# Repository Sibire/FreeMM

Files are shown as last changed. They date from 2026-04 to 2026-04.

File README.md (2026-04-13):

# DIYgitizer

A Do-It-Yourself 5-DOF digitizer arm / coordinate measuring machine for under $200.

DIYgitizer arm

# So what is it?

The DIYgitizer is a passive (no motors), manually-operated measuring arm. Magnetic encoders within each joint track their angles, forward kinematics computes the probe tip position in three dimensions, and a desktop app captures the data and works its various magics.

## Why on Earth would you make this?

For roughly the same reasons I did. I got tired of eyeballing dimensions on things I bought, had a drone frame I couldn't find a drawing of, and figured I could use a little project to keep myself busy. Also, I didn't feel like buying a 3D scanner, don't own an iPhone, and didn't have the cash to blow on a multi-thousand-dollar machine. I figured I could get around some accuracy issues by making adjustable drawings, instead. Now we're here.

**Modes of Operation**

- **CMM Mode** — Like any coordinate measurement machine, this mode captures individual points, measures the distances between them, and exports them for review. It's not nearly as accurate as a $35,000 stand-alone device might be, but it's also orders of magnitude cheaper, so there's that.
- **3D Digitizer Mode** — Run the probe over a surface to scan it continuously, building a point cloud, mesh, or parametric model. Then, export to Fusion (or whatever you're using) as a PLY, STL, or STEP file.
- **2D Trace Mode** — Trace an object's outline, auto-detecting lines, arcs, and circles, and export their dimensions as a DXF or SVG drawing.
  
To maximize the user's ability to compensate for measurement errors, all shapes are broken down into their most basic primitives. This means lines, arcs, circles, planes, cylinders, spheres, and the like, all with dimensioned offsets. No splines, because manually editing those when you don't know the existing dimensions is exactly the sort of headache I'm building this entire project specifically to avoid. Every measurement is an individual dimension you can edit in Fusion, or some other software of your choice.

## Hardware

### Kinematic Chain

```
Base Plate (clamped to desk)
  └─ J1: Base Yaw (360°)
       └─ Turret
            └─ J2: Shoulder Pitch (±105°)
                 └─ Upper Arm (300mm aluminum tube)
                      └─ J3: Elbow Pitch (±145°)
                           └─ Forearm (300mm aluminum tube)
                                └─ J4: Wrist Pitch (360°)
                                     └─ J5: Wrist Pitch 2 — perpendicular to J4 (±145°)
                                          └─ Probe (1mm ruby ball)
```

### Electronics

| Component | Details |
|---|---|
| 1x MCU | ESP32 (38-pin) |
| 5x Encoders | AS5600 (12-bit magnetic, I2C. 23x23mm with M3 holes 16mm apart) |
| 1x I2C Mux | TCA9548A Breakout Board(resolves shared AS5600 address) |
| 1x Display | 0.96" SSD1306 OLED I2C (Make sure yours is square, 28x28mm) |
| 3x Buttons | Sample (GPIO 26), Mode (GPIO 27), Foot Pedal Sample (GPIO 25) |

### Bill of Hardware

REQUIRED:
| Component | Details |
|---|---|
| 2x 8mm OD x 300mm Aluminum tubing | Arm structure |
| 4x M2x6mm Screws | OLED mount |
| 22x M3x6mm Screws | 4x5 Encoder mount, 2x Mux mount |
| 6x M5x12mm Screws | 4x Base clamp. 2x Foot pedal |
| 1x 2mm Thread insert | Probe swivel (4mm Preferred) |
| 1x M2 1mm Probe Tip | Adjust J5 length to center of probe tip |
| Two-wire shielded cable | Still working out exact length |
| 22 AWG wire | See above |
| Double-sided tape | Keep the MCU in place) |
| A whole lot of zipties and heat shrink | Tidying things up |
| Hot Glue | Gluing the buttons in place, literally whatever else it might be used for |

PREFERRED:
| Component | Details |
|---|---|
| 4x M5 Thread inserts | Base clamp, part is 3.75mm thick, so smaller the better, but it's not terribly critical |
| 2x M10 Thread inserts | Base clamp, in case print tolerances are off for the table clamping bolts |
| 2x M10x75mm Bolts | Base clamp, see above |

### Print List

| Component | Details |
|---|---|
| 1x Base | Holds it all together |
| 1x Base Clamp | Fits into base for desk mounting |
| 2x Base Clamp Screw | Secures base clamp to desk |
| 2x Sensor Swivel | Contains a magnet to interface with one encoder, and the mount for another |
| 2x Sensor Elbow | Contains a mount for an encoder, a slot for 8mm tubing, and sights for alignment with sensorless swivel |
| 2x Sensorless Swivel | Contains a magnet to interface with an encoder, a slot for 8mm tubing, and signts for alignment with elbow |
| 1x Probe Swivel | Holds sample button and probe tip |
| 5x Encoder Lid | Covers encoder compartments |
| 1x Display Lid | Covers OLED circuitry |
| 1x Base Lid | Covers MCU/Mux compartment |
| 1x Foot Pedal Base | It's a pedal base |
| 1x Foot Pedal Top | It's a pedal top |
| 1x Calibration Stop | Slots into base to lock turret alignment for calibration |

All printed parts are PETG (40% infill, 4 walls) with the exception of the Base (10%) and the Base Clamp (15%). You can find an existing set of slices (albeit for an Ender 5 Pro with a MicroSwiss all-metal-hotend and direct drive setup on TH3D firmware) within the repo. Total cost of $Free.99 to $200, depending on what you have on hand.

If your Mux board doesn't fit the base lid's screw posts, use the bare lid and some tape.

## Software

### Desktop App (Python / PyQt5)

```
cd desktop
pip install -r requirements.txt
python run.py
```

Check **Simulator** and click **Connect** to test without hardware.

**Features:**
- Live XYZ + joint angle readout
- CMM mode with point table and dimension list
- 3D viewport (OpenGL) with point cloud, mesh preview, and feature detection overlays
- 2D canvas with fitted features and dimension annotations
- Calibration wizard (1-2-3 block)
- Measurement rounding: 1mm / 0.1mm / 0.01mm (user setting)
- Export: DXF, SVG, PLY, CSV, STL, STEP

**Dependencies:** PyQt5, PyOpenGL, pyserial, numpy, scipy, ezdxf, trimesh. Optional: open3d (mesh), cadquery (STEP).

### Firmware (C++ / PlatformIO)

```
cd firmware
pio run                  # compile
pio run --target upload  # flash to ESP32
pio device monitor       # watch serial output
```

Streams `ANGLES,j1,j2,j3,j4,j5` at ~200Hz over USB serial (115200 baud). Responds to commands: `p` (sample point), `t` (toggle trace), `1`/`2`/`3` (set trace plane), `r` (reset).

### Link Lengths

The forward kinematics uses center-to-center joint distances. These are defined in `firmware/src/config.h` and `desktop/diygitizer/config.py`:

```
BASE_HEIGHT = 38mm      # base plate surface to J2 axis
UPPER_ARM   = 330.1mm   # J2 to J3
FOREARM     = 330.1mm   # J3 to J4
WRIST_LINK  = 36mm      # J4 to J5
PROBE_LEN   = 77.3mm    # J5 to ruby ball center
```

## Calibration

Use a 1-2-3 block (25.4 × 50.8 × 76.2mm). They're cheap, precise enough, and easy to find. The app's calibration wizard will walk you through touching each face, then compute scale factors and joint offsets to minimize error. Without precision parts, you'll want to do this *often*.

## Accuracy

- AS5600: ±1° typical (12-bit)
- Expected tip accuracy: ±1-2mm calibrated, ±3-5mm uncalibrated
- Probe compensation: 0.5mm ball radius, applied automatically
- This is a digitizer, not a metrology instrument. It's designed to beat the Mk. 1 Eyeball, that's about it.

## Project Structure

```
DIYgitizer/
├── firmware/                    # ESP32 PlatformIO project
│   ├── platformio.ini
│   └── src/
│       ├── main.cpp             # Main loop
│       ├── config.h             # Pins, link lengths, constants
│       ├── encoders.*           # AS5600 via TCA9548A mux
│       ├── kinematics.*         # 5-DOF forward kinematics
│       ├── serial_protocol.*    # USB serial protocol
│       ├── buttons.*            # Debounced input
│       ├── display.*            # SSD1306 OLED
│       └── modes.*              # State machine
│
└── desktop/                     # Python desktop app
    ├── run.py                   # Entry point
    ├── requirements.txt
    └── diygitizer/
        ├── app.py               # MainWindow + DataStore
        ├── config.py            # Link lengths, rounding
        ├── connection/          # Serial + simulator
        ├── models/              # Data classes
        ├── modes/
        │   ├── cmm/             # Point capture + dimensions
        │   ├── digitizer/       # 3D scan + mesh + features
        │   └── trace/           # 2D trace pipeline
        ├── calibration/         # 1-2-3 block wizard
        ├── export/              # DXF, SVG, PLY, STL, STEP, CSV
        └── widgets/             # Shared UI components
```

## Status

- [x] Full CAD assembly in Fusion 360
- [x] ESP32 firmware (5-DOF FK, serial protocol, OLED, buttons)
- [x] Desktop app with all three modes
- [x] Geometry pipeline (2D feature fitting)
- [x] 3D feature detection (RANSAC plane/sphere/cylinder)
- [x] Export: DXF, SVG, PLY, STL, STEP, CSV
- [x] Calibration wizard
- [x] Built-in simulator
- [ ] Print and assemble hardware
- [ ] Measure actual link lengths from assembly
- [ ] First real-hardware test
- [ ] Tune calibration procedure

## License

TBD

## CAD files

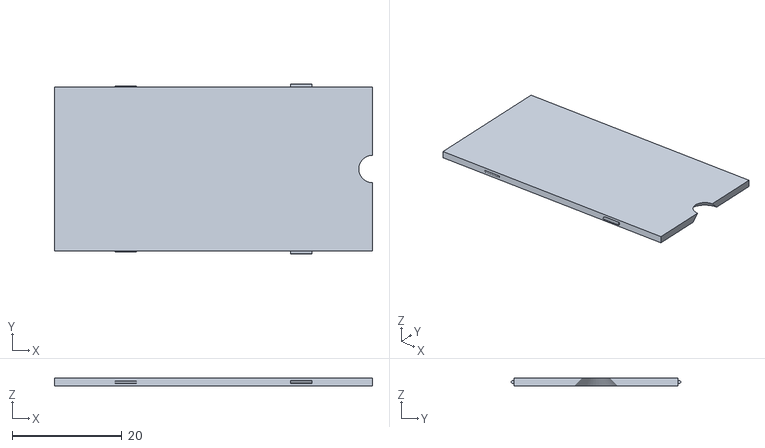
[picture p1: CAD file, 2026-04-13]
models/STL Files/Base Lid Bare.stl
58.0 x 31.0 x 1.50

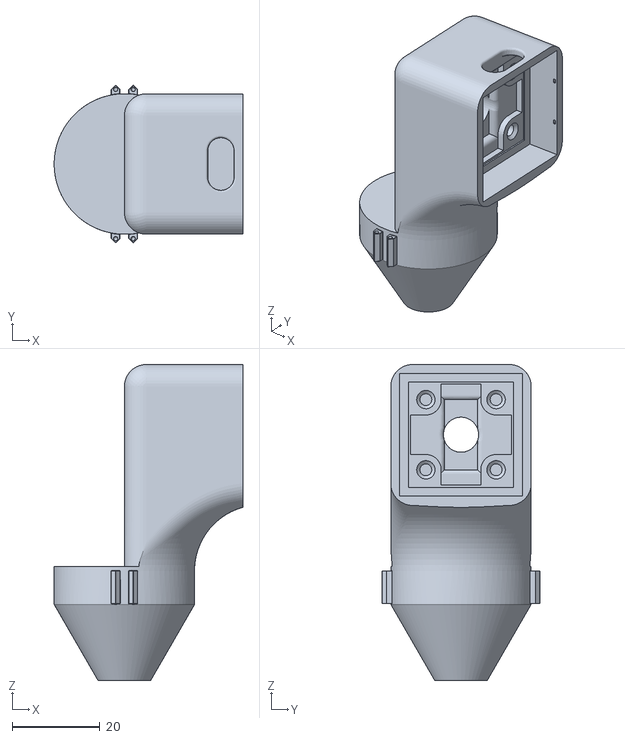
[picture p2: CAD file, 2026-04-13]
models/STL Files/Sensor Elbow.stl
43.0 x 35.9 x 72.0

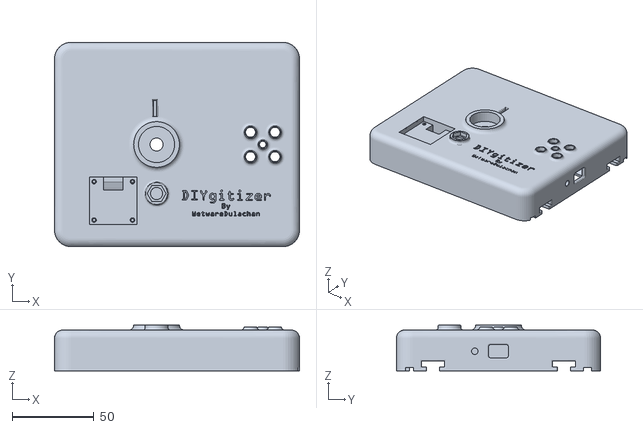
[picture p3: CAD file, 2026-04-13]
models/STL Files/Base.stl
150.0 x 125.0 x 28.0

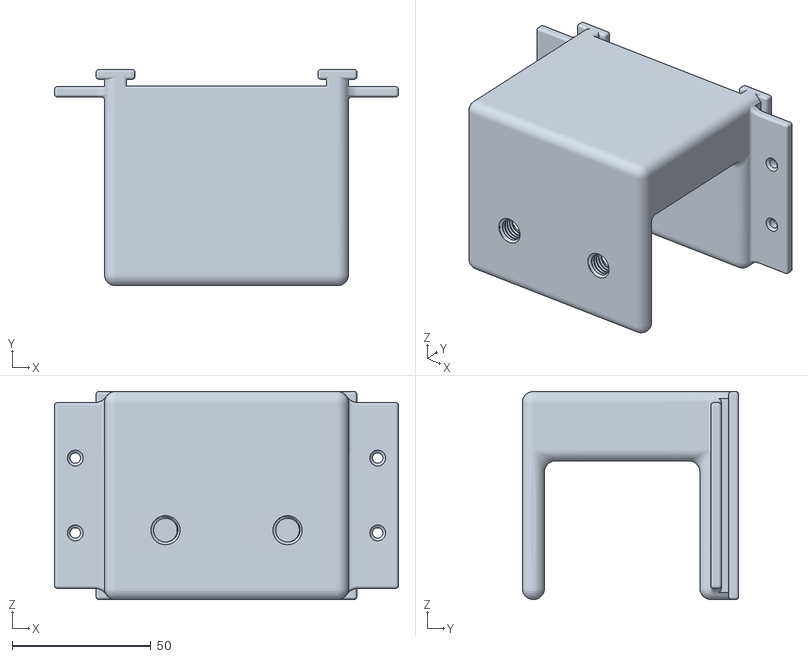
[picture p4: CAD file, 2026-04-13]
models/STL Files/Base Clamp.stl
124.0 x 78.0 x 75.0

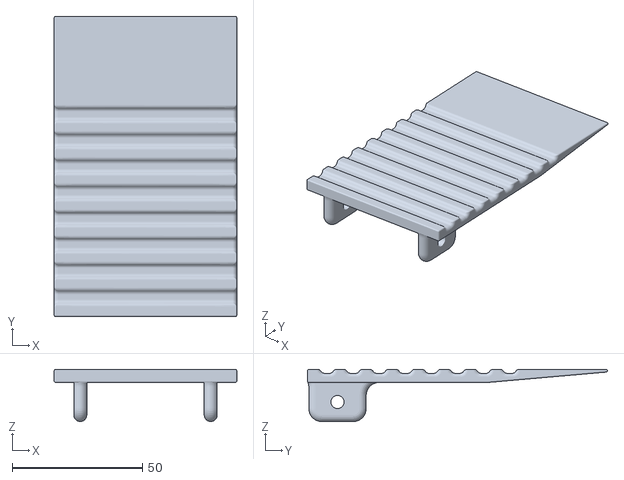
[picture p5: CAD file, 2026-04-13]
models/STL Files/Foot Pedal Top.stl
70.0 x 115.0 x 20.0

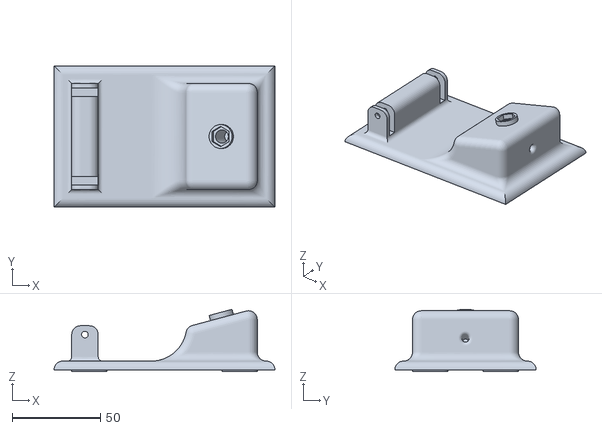
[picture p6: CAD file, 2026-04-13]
models/STL Files/Foot Pedal Base.stl
125.0 x 80.0 x 35.3

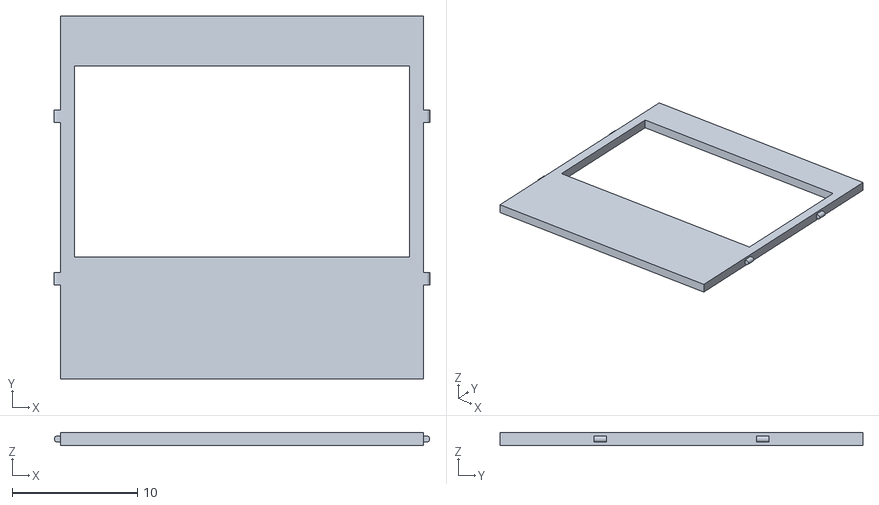
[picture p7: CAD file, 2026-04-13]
models/STL Files/Display Lid.stl
30.0 x 29.0 x 1.00

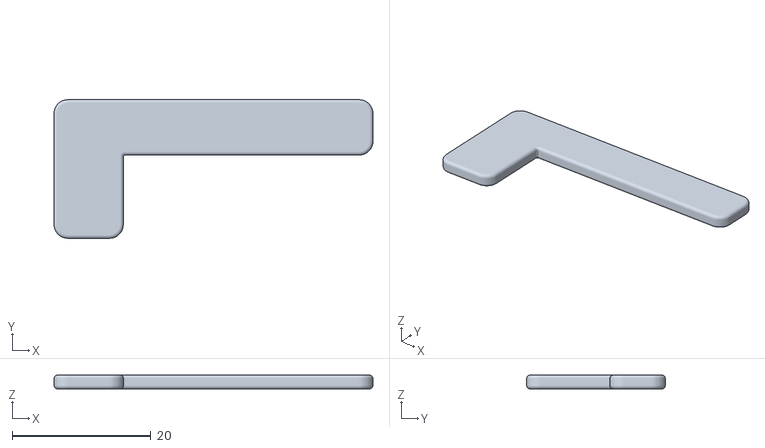
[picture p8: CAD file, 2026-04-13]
models/STL Files/Calibration Stop.stl
46.0 x 20.0 x 2.00

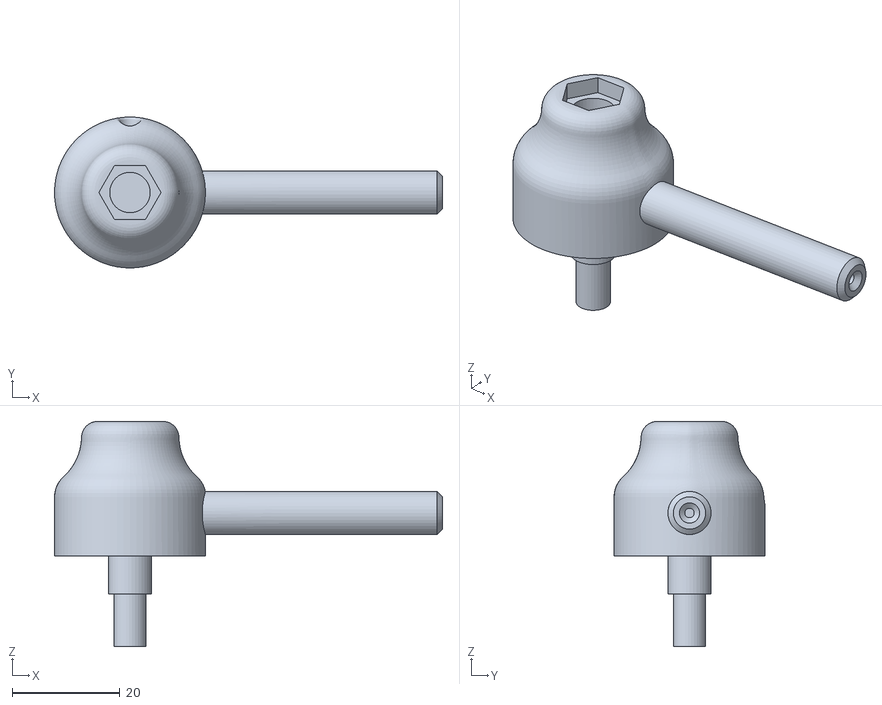
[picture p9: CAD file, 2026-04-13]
models/STL Files/Probe Swivel.stl
72.0 x 28.0 x 41.8

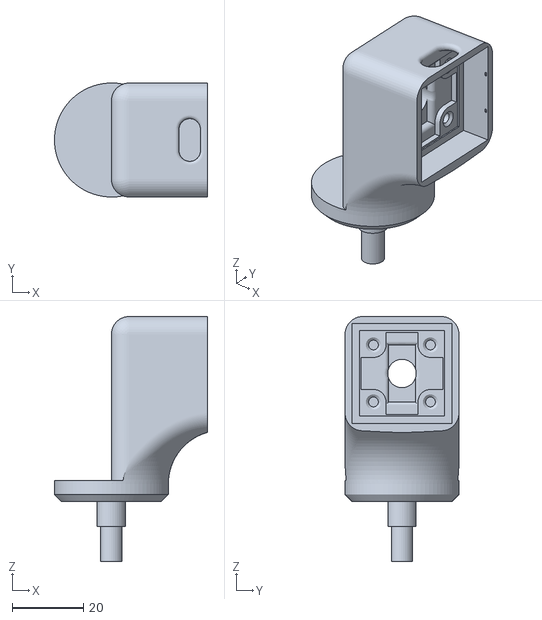
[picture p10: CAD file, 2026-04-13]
models/STL Files/Sensor Swivel.stl
43.0 x 32.0 x 68.8

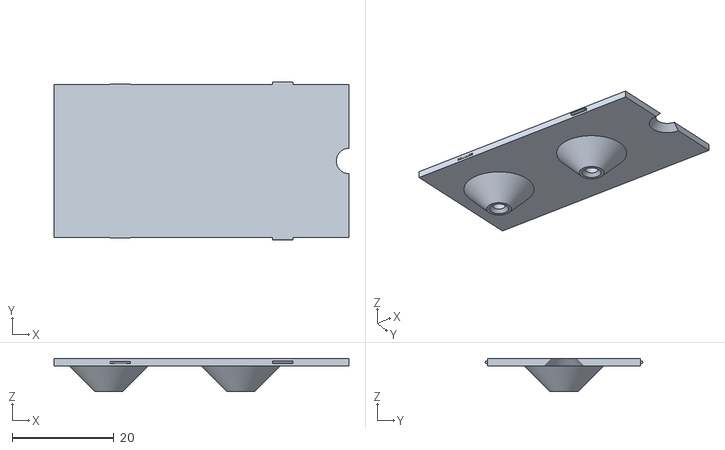
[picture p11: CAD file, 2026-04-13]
models/STL Files/Base Lid.stl
58.0 x 31.0 x 6.50

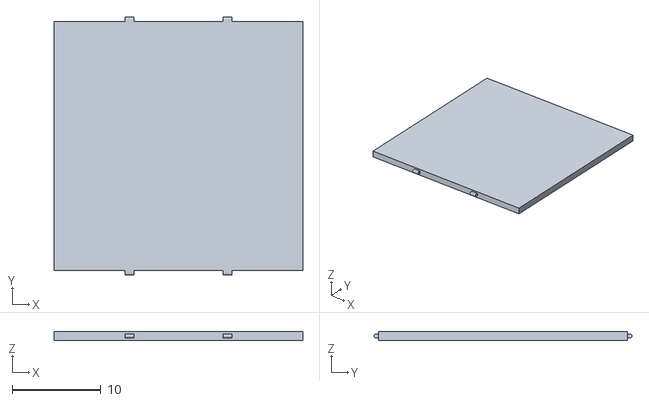
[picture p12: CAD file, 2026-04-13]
models/STL Files/Encoder Lid.stl
28.0 x 29.0 x 1.00

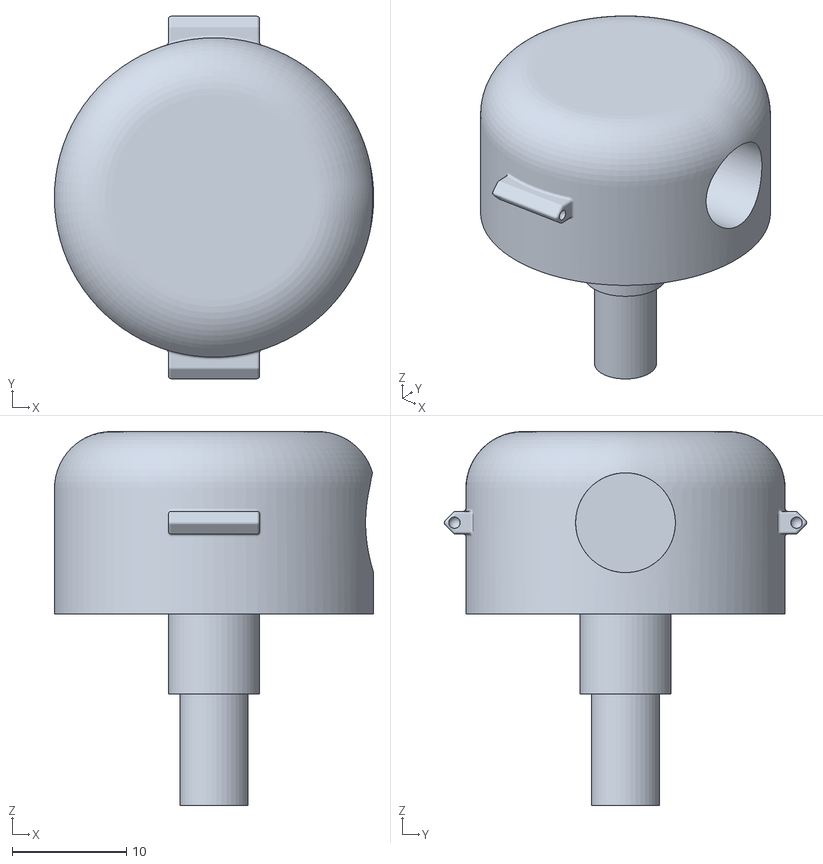
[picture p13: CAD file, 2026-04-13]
models/STL Files/Sensorless Swivel.stl
28.0 x 31.8 x 32.8

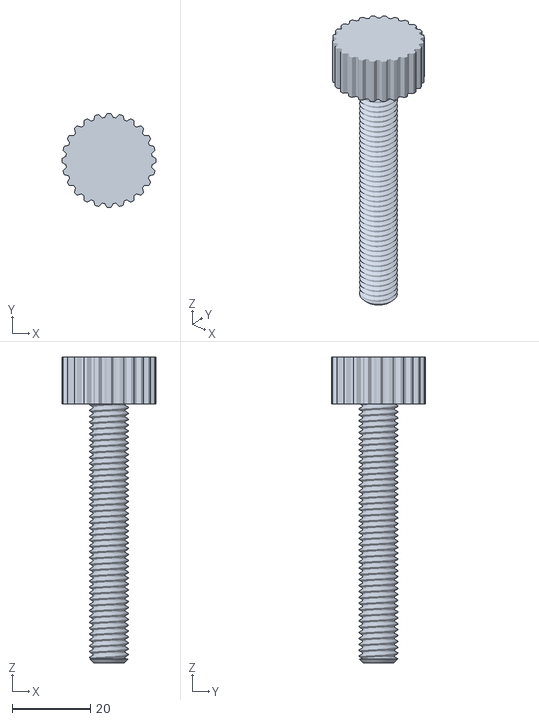
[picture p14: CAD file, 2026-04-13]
models/STL Files/Clamp Screw.stl
24.0 x 24.0 x 78.0

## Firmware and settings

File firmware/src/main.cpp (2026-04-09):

#include <Arduino.h>
#include <Wire.h>
#include "config.h"
#include "encoders.h"
#include "kinematics.h"
#include "serial_protocol.h"
#include "buttons.h"
#include "display.h"
#include "modes.h"

void setup() {
    Serial.begin(SERIAL_BAUD);

    // I2C is initialized inside initEncoders (Wire.begin + setClock)
    initEncoders();
    initDisplay();
    initButtons();
    initModes();

    sendStatus("DIYgitizer ready");
}

void loop() {
    float angles[5];

    if (!readAllJoints(angles)) {
        // Sensor read failed — skip this cycle
        return;
    }

    FKResult fk = computeFK(angles);

    // Continuous angle stream
    sendAngles(angles);

    // Read buttons
    updateButtons();
    bool sample = samplePressed();
    bool mode   = modePressed();

    // Check serial commands
    char cmd = parseCommand();

    // Cycle display page on mode button press
    if (mode) {
        cycleDisplayPage();
    }

    // Run mode state machine (handles 'p', 't', '1'/'2'/'3', 'r', and sample button)
    handleModeLogic(angles, fk, cmd, sample);

    // Update OLED (rate-limited internally to OLED_UPDATE_INTERVAL_MS)
    updateDisplay(angles, fk.tip, getPointCount(), getMode());
}

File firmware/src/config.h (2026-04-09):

#pragma once

#include <Arduino.h>

// --- Pin Assignments ---
#define PIN_SDA        21
#define PIN_SCL        22
#define PIN_BTN_SAMPLE 26
#define PIN_BTN_MODE   27
#define PIN_BTN_FOOT   25

// --- I2C Addresses ---
#define ADDR_TCA9548A  0x70
#define ADDR_AS5600    0x36
#define ADDR_OLED      0x3C

// --- AS5600 Registers ---
#define REG_RAW_ANGLE  0x0E   // 12-bit raw angle (2 bytes, big-endian)
#define REG_AGC        0x1A   // Automatic gain control

// --- Display ---
#define SCREEN_WIDTH   128
#define SCREEN_HEIGHT  64

// --- Link Lengths (mm) — measured from Fusion assembly ---
#define BASE_HEIGHT    38.0f
#define UPPER_ARM     330.1f
#define FOREARM       330.1f
#define WRIST_LINK     36.0f
#define PROBE_LEN      77.3f
#define BALL_RADIUS     0.5f

// --- Joint Count ---
#define NUM_JOINTS     5

// --- Serial ---
#define SERIAL_BAUD    115200

// --- I2C ---
#define I2C_CLOCK      400000

// --- Timing ---
#define OLED_UPDATE_INTERVAL_MS  100
#define DEBOUNCE_MS               20
#define TRACE_MIN_DIST_DEFAULT    1.0f  // mm

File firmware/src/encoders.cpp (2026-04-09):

#include "encoders.h"
#include "config.h"
#include <Wire.h>

void selectMuxChannel(uint8_t channel) {
    Wire.beginTransmission(ADDR_TCA9548A);
    Wire.write(1 << channel);
    Wire.endTransmission();
}

uint16_t readAS5600Raw() {
    Wire.beginTransmission(ADDR_AS5600);
    Wire.write(REG_RAW_ANGLE);
    if (Wire.endTransmission(false) != 0) {
        return 0xFFFF; // error sentinel
    }

    Wire.requestFrom((uint8_t)ADDR_AS5600, (uint8_t)2);
    if (Wire.available() < 2) {
        return 0xFFFF; // error sentinel
    }

    uint16_t highByte = Wire.read();
    uint16_t lowByte  = Wire.read();
    uint16_t raw = ((highByte & 0x0F) << 8) | lowByte; // 12-bit value
    return raw;
}

uint8_t readAS5600AGC() {
    Wire.beginTransmission(ADDR_AS5600);
    Wire.write(REG_AGC);
    if (Wire.endTransmission(false) != 0) {
        return 0;
    }

    Wire.requestFrom((uint8_t)ADDR_AS5600, (uint8_t)1);
    if (Wire.available() < 1) {
        return 0;
    }

    return Wire.read();
}

void initEncoders() {
    Wire.begin(PIN_SDA, PIN_SCL);
    Wire.setClock(I2C_CLOCK);

    // Verify TCA9548A mux responds
    Wire.beginTransmission(ADDR_TCA9548A);
    if (Wire.endTransmission() != 0) {
        Serial.println("# ERROR: TCA9548A mux not found at 0x70");
    } else {
        Serial.println("# TCA9548A mux found");
    }

    // Scan channels 0-4 for AS5600 sensors
    for (uint8_t ch = 0; ch < NUM_JOINTS; ch++) {
        selectMuxChannel(ch);
        Wire.beginTransmission(ADDR_AS5600);
        if (Wire.endTransmission() == 0) {
            uint8_t agc = readAS5600AGC();
            Serial.printf("# J%d (CH%d): AS5600 OK, AGC=%d\n", ch + 1, ch, agc);
        } else {
            Serial.printf("# J%d (CH%d): AS5600 NOT FOUND\n", ch + 1, ch);
        }
    }
}

bool readAllJoints(float angles[5]) {
    for (uint8_t ch = 0; ch < NUM_JOINTS; ch++) {
        selectMuxChannel(ch);
        uint16_t raw = readAS5600Raw();
        if (raw == 0xFFFF) {
            return false;
        }
        angles[ch] = (float)raw * 2.0f * PI / 4096.0f;
    }
    return true;
}

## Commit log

2026-04-09 Add complete firmware and desktop app for DIYgitizer arm
    ESP32 firmware:
    - AS5600 sensor reading via TCA9548A I2C mux (5 joints)
    - 5-DOF forward kinematics (J1 yaw, J2-J4 pitch, J5 perpendicular)
    - Serial protocol at 115200 baud with ANGLES/POINT/TRACE streaming
    - SSD1306 OLED display, 3 buttons (sample/mode/foot pedal)
    PyQt5 desktop app with three modes:
    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
2026-04-09 Rebuild DIYgitizer with full 3-mode desktop app and ESP32 firmware
    Complete rewrite with clean package structure:
    Firmware (ESP32/PlatformIO):
    - 5x AS5600 encoders via TCA9548A I2C mux
    - 5-DOF forward kinematics (J1=yaw, J2-J4=pitch, J5=perpendicular)
    - Serial protocol: ANGLES/POINT/TRACE at 115200 baud
    - SSD1306 OLED display, debounced buttons, state machine
    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
2026-04-09 Replace random simulator with manual sliders and test shapes
    Simulator now has three modes instead of random sine-wave flailing:
    - Manual: joint sliders in the UI, arm stays where you put it
    - Predefined shapes: rectangle, circle (2D trace tests), cylinder,
    sphere (3D scan tests) with proper IK (0.00mm FK roundtrip error)
    - Idle: gentle oscillation for demo purposes
    Adds SimulatorPanel widget with mode selector, joint sliders, and
    per-shape info text. Panel auto-shows when simulator connects.
    https://claude.ai/code/session_01KbW7gpyymfoLaihk16Lw6n
    [simulator.py]
2026-04-09 Fix 2D trace shapes to XY plane and slow shape playback to ~20%
    Rectangle and circle now trace in XY (z=constant) instead of XZ.
    Shape durations increased 5x (rectangle/circle 5s, cylinder/sphere 10s)
    so the arm moves at a realistic pace.
    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
    [simulator.py]
2026-04-09 Wire speed dial to simulator and fix 3D shape smoothness
    - Speed dial now emits speed_changed signal, wired through app.py
    to simulator.set_speed(). Multiplier scales time parameter.
    - Cylinder/sphere shapes now use smooth spiral interpolation instead
    of snapping to discrete grid points (was causing jerky motion).
    - All shapes respect the speed multiplier (0.1x to 5.0x).
    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
    [simulator.py]
2026-04-09 Add box/star/full-sphere shapes and fix trace line color
    New simulator shapes:
    - Star (5-pointed, 2D trace test)
    - Box (50x30x40mm rectangular prism, 3D scan test)
    - Sphere now covers full surface (south pole to north pole)
    2D trace raw line color changed from gray to green for visibility.
    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
    [simulator.py]
2026-04-09 Update link lengths to actual Fusion measurements
    BASE_HEIGHT: 50 → 38mm
    UPPER_ARM: 150 → 330.1mm
    FOREARM: 130 → 330.1mm
    WRIST_LINK: 30 → 36mm
    PROBE_LEN: 20 → 77.3mm
    Updated in firmware config.h, desktop config.py, and README.
    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
2026-04-09 Fix mesh builder and scale grid to arm reach
    Mesh builder:
    - Default to ball_pivoting instead of Poisson (no fake closure faces)
    - For Poisson, add density-based trimming to remove invented surfaces
    - Scale normal estimation radius to point cloud extent (was hardcoded
    10mm, way too small for 773mm arm)
    - Add multiple ball radii for BPA to handle varying point density
    - Fallback gracefully if reconstruction produces no faces
    3D viewport:
    - Grid expanded from ±200mm to ±800mm with 100mm steps
    - Axis indicators extended to 200mm
    - Default camera distance increased to 1200mm to see full workspace
    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
2026-04-13 Model Upload
    Added current model iterations and pre-sliced files for an Ender 5 Pro running Polymaker PETG with a Micro Swiss direct drive mod and all-metal hotend.
    [Base Clamp.stl, Base Lid Bare.stl, Base Lid.stl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]
2026-04-13 BoM Adjustments
2026-04-13 Remove probe details from README
    Removed probe description from hardware list.
2026-04-13 Revise electronics and add print list in README
    Updated hardware components list and added a print list section in the README.
2026-04-13 Mild Spelling Mistake
    [Calibration Stop.stl]
2026-04-13 Revise electronics component details in README
    Updated component details for clarity and added note about Mux board fitting.
2026-04-13 Add hot glue usage to components list
